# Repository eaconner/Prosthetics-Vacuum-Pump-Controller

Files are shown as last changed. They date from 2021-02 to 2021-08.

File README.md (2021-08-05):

# Prosthetics Vacuum Pump Controller

## Introduction

Designed to maintain a set vacuum pressure for prosthetic arms and legs.

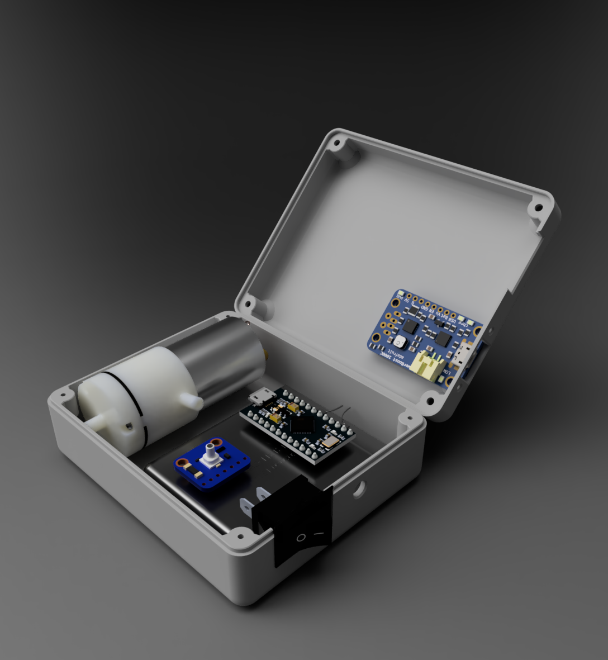
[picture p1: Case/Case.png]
3D Printed Case


## Dependencies

[Adafruit MPRLS Library](https://github.com/adafruit/Adafruit_MPRLS)

## Author

Eric Conner (Eric@EricConner.net)

## License

### MIT license

Permission is hereby granted, free of charge, to any person obtaining a copy of this software and associated documentation files (the "Software"), to deal in the Software without restriction, including without limitation the rights to use, copy, modify, merge, publish, distribute, sublicense, and/or sell copies of the Software, and to permit persons to whom the Software is furnished to do so, subject to the following conditions:

The above copyright notice and this permission notice shall be included in all copies or substantial portions of the Software.

THE SOFTWARE IS PROVIDED "AS IS", WITHOUT WARRANTY OF ANY KIND, EXPRESS OR IMPLIED, INCLUDING BUT NOT LIMITED TO THE WARRANTIES OF MERCHANTABILITY, FITNESS FOR A PARTICULAR PURPOSE AND NONINFRINGEMENT. IN NO EVENT SHALL THE AUTHORS OR COPYRIGHT HOLDERS BE LIABLE FOR ANY CLAIM, DAMAGES OR OTHER LIABILITY, WHETHER IN AN ACTION OF CONTRACT, TORT OR OTHERWISE, ARISING FROM, OUT OF OR IN CONNECTION WITH THE SOFTWARE OR THE USE OR OTHER DEALINGS IN THE SOFTWARE.

## Changes

- 2021.0628.0 - Added min/max set points
- 2021.0221.0 - Revised Pump class to define pump pin when pump is initilized
- 2021.0220.0 - Set DEBUG to false and misc. other changes
- 2021.0219.0 - Added option to specify on and off times for Pump
- 2021.0218.1 - Added destructor for Pump class
- 2021.0218.0 - Initial release

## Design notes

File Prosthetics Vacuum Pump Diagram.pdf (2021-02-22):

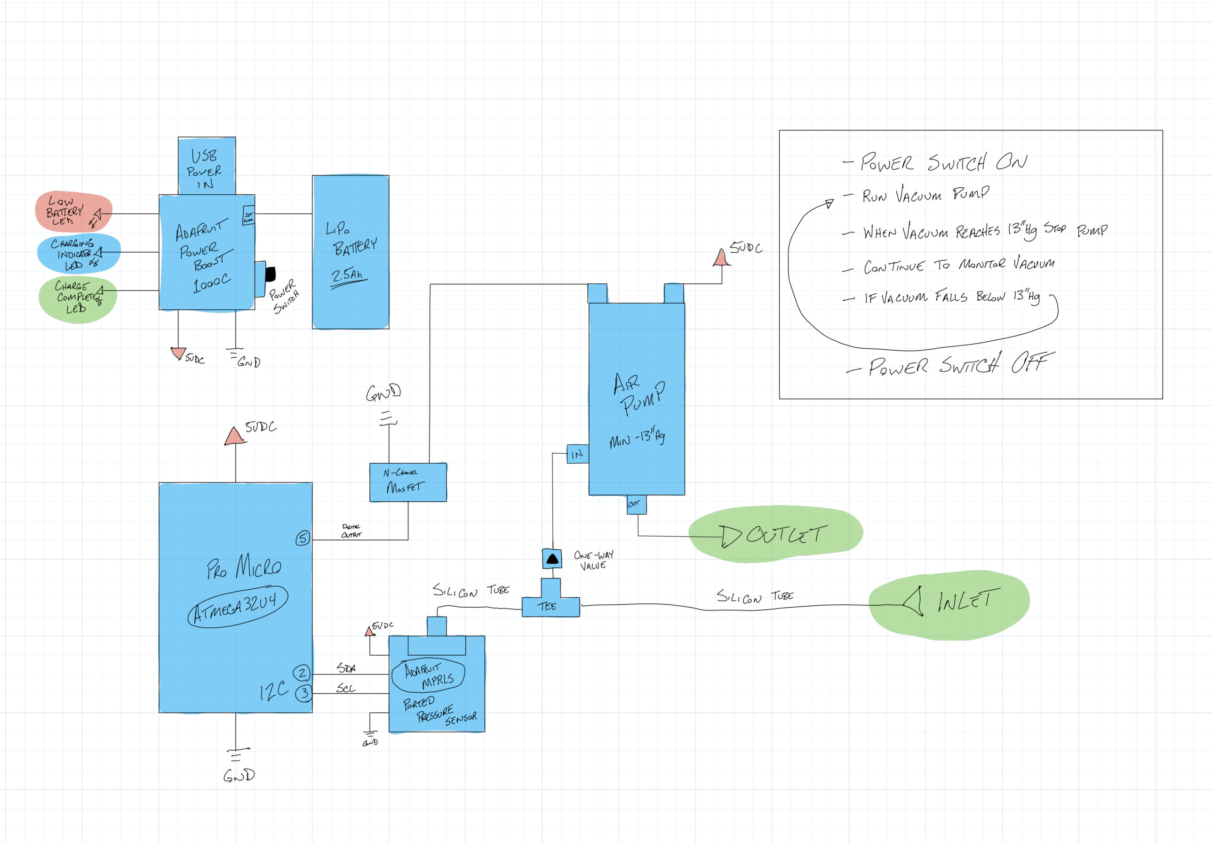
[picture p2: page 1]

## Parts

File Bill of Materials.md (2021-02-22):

# Prosthetics Vacuum Pump Controller

## Bill of Materials

- [Adafruit PowerBoost 1000 Charger](https://www.adafruit.com/product/2465)
- [Adafruit MPRLS Ported Pressure Sensor Breakout](https://www.adafruit.com/product/3965)
- [Air Pump and Vacuum DC Motor](https://www.adafruit.com/product/4699)
- [Silicone Tubing for Air Pumps and Valves - 3mm ID](https://www.adafruit.com/product/4661)
- [T-Connector For Silicone Tubing](https://www.adafruit.com/product/4662)
- [Lithium Ion Polymer Battery - 3.7v 2500mAh](https://www.adafruit.com/product/328)
- [N-channel power MOSFET - 30V / 60A](https://www.adafruit.com/product/355)
- [Pro Micro 5V 16MHz Development Board](https://amazon.com/gp/product/B07FXCTVQP)
- [SPST Toggle Switch](https://amazon.com/gp/product/B08F816MB4)
- [4mm Check Valve](https://www.amazon.com/gp/product/B08HYVKTLX)

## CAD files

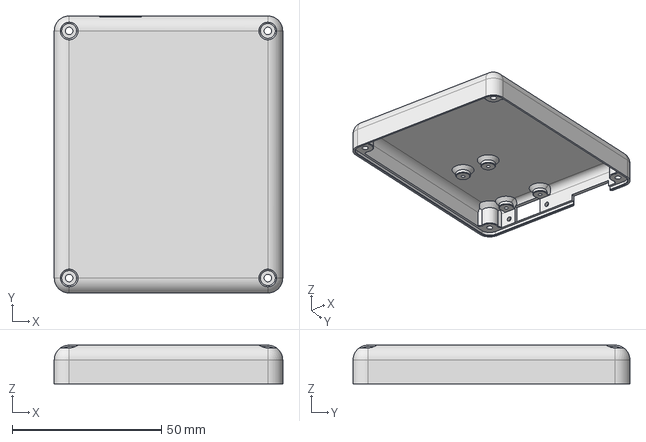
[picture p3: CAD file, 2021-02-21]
Case/Top.step
76.7 x 92.9 x 13.0 mm

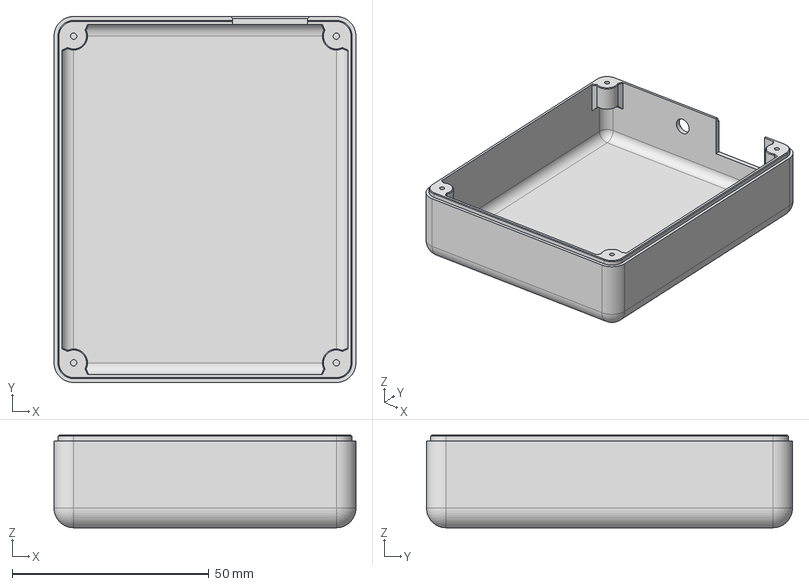
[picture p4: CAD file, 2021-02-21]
Case/Bottom.step
76.7 x 92.9 x 23.5 mm

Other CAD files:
Case/Bottom.stl
Case/Top.stl

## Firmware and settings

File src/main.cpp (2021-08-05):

/**
 * @file main.cpp
 * 
 * @author Eric Conner (Eric@EricConner.net)
 * @version 2021.0628.0
 * @copyright Copyright (c) 2021
 * 
 * @mainpage Prosthetics Vacuum Pump Controller
 * 
 * @section introduction Introduction
 * 
 * Designed to maintain a set vacuum pressure for prosthetic arms and legs.
 * 
 * @section dependencies Dependencies
 * 
 * [Adafruit MPRLS Library] (https://github.com/adafruit/Adafruit_MPRLS)
 * 
 * @section author Author
 * 
 * Eric Conner (Eric@EricConner.net)
 * 
 * @section license License
 * 
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
 * The above copyright notice and this permission notice shall be included in all copies or substantial portions of the Software.
 * 
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
 * @section changes Changes
 * 
 * 2021.0628.0 - Added min/max set points
 * 
 * 2021.0221.0 - Revised Pump class to define pump pin when pump is initilized
 * 
 * 2021.0220.0 - Set DEBUG to false and misc. other changes
 * 
 * 2021.0219.0 - Added option to specify on and off times for Pump
 * 
 * 2021.0218.1 - Added destructor for Pump class
 * 
 * 2021.0218.0 - Initial release
 */

#include "main.h"
#include "pump.h"

Adafruit_MPRLS mpr = Adafruit_MPRLS();  // Initilize the Pressure Sensor
Pump pump = Pump(pumpPin);  // Initilize the Pump

/**
 * @brief Standard Arduino setup function, this initilizes everything and then jumps to loop().
 */
void setup() {
    if (DEBUG) {
        Serial.begin(115200);  // Setup serial connection for displaying text if we are in debug mode
        Serial.println("Prosthetic Vacuum Pump - v2021.0628.0");
    }

    // Start the MPRLS pressure sensor
    if(!mpr.begin()) {
        // Wait for sensor to connect
        while(1) {
            delay(10);
            Serial.println("Waiting for sensor...");
        }
    }

   delay(2500);

   wdt_reset();
   wdt_enable(WDTO_2S);
}

/**
 * @brief Standard Arduino loop fuction, this is our main code loop.
 */
void loop() {
    if (getPressure() >= setMaxPressure) {  // If the pressure is greater than the setMinPressure turn the pump on.
        pump.On();
    }

    if (getPressure() <= setMinPressure) {  // If the pressure is greater than the setMaxPressure turn the pump off.
        pump.Off();
    }

    delay(750);
    wdt_reset();
}

/**
 * @brief Get the Pressure value from the Pressure Sensor in hPa.
 * 
 * @return float 
 */
float getPressure() {
    float pressure_hPa = mpr.readPressure();

    if (DEBUG) {
        Serial.print("Pressure (hPa): ");
        Serial.println(pressure_hPa);
    }

    return pressure_hPa;  // Return the pressure value
}

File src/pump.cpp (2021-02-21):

/**
 * @file pump.cpp
 * 
 * @author Eric Conner (Eric@EricConner.net)
 * @copyright Copyright (c) 2021
 * 
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
 * The above copyright notice and this permission notice shall be included in all copies or substantial portions of the Software.
 * 
 * THE SOFTWARE IS PROVIDED "AS IS", WITHOUT WARRANTY OF ANY KIND, EXPRESS OR IMPLIED, INCLUDING BUT NOT LIMITED TO THE WARRANTIES OF
 * MERCHANTABILITY, FITNESS FOR A PARTICULAR PURPOSE AND NONINFRINGEMENT. IN NO EVENT SHALL THE AUTHORS OR COPYRIGHT HOLDERS BE LIABLE FOR
 * ANY CLAIM, DAMAGES OR OTHER LIABILITY, WHETHER IN AN ACTION OF CONTRACT, TORT OR OTHERWISE, ARISING FROM, OUT OF OR IN CONNECTION WITH
 * THE SOFTWARE OR THE USE OR OTHER DEALINGS IN THE SOFTWARE.
 */

#include "pump.h"

/**
 * @brief Construct a new Pump::Pump object
 * 
 * @param pumpPin Output pin that the pump is connected to
 * @param onTime Maximum time to run the pump in milliseconds, default: 10,000
 * @param offTime Minimum time to stop the pump to cool down, default: 5,000
 */
Pump::Pump(int pumpPin, unsigned short onTime, unsigned short offTime) {
    Pump::pumpPin = pumpPin;
    Pump::onTimer = 0;  // Reset onTimer to 0
    Pump::offTimer = 0;  // Reset offTimer to 0
    Pump::status = STOPPED;
    Pump::maxOnTime = onTime;
    Pump::minOffTime = offTime;
    pinMode(Pump::pumpPin, OUTPUT);  // Setup the output pin for Pump
    digitalWrite(Pump::pumpPin, LOW);  // Seting the Pump output pin LOW turns the Pump off
}

/**
 * @brief Destroy the Pump::Pump object
 */
Pump::~Pump() {
    digitalWrite(Pump::pumpPin, LOW);  // Seting the Pump output pin LOW turns the Pump off
    Pump::status = STOPPED;
}

/**
 * @brief Call for the pump to turn on, will only turn on if it has been off for at least 5 seconds
 */
void Pump::On() {
    // If the pump is off and cooled down turn the pump on, set the status to running and start the running timer
    if (Pump::status == STOPPED) {
        digitalWrite(Pump::pumpPin, HIGH);
        Pump::status = RUNNING;
        Pump::onTimer = millis();
    }
    
    if (Pump::status == RUNNING) {
        // If the pump has been running for 10 seconds turn it off to prevent overheating
        if (millis() - Pump::onTimer >= Pump::maxOnTime) {
            Pump::Off();
        }
    }

    if (Pump::status == COOLDOWN) {
        // If the pump has been cooled down for 5 seconds set the status to stopped
        if (millis() - Pump::offTimer >= Pump::minOffTime) {
            Pump::status = STOPPED;
        }
    }
}

/**
 * @brief Call for the pump to instantly turn off
 */
void Pump::Off() {
    // If the pump is running turn it off and start the cooldown timer
    if (Pump::status == RUNNING) {
        digitalWrite(Pump::pumpPin, LOW);
        Pump::offTimer = millis();
        Pump::status = COOLDOWN;
    }
    
    if (Pump::status == COOLDOWN) {
        // If the pump has been cooled down for 5 seconds set the status to stopped
        if (millis() - Pump::offTimer >= Pump::minOffTime) {
            Pump::status = STOPPED;
        }
    }
}

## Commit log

2021-02-18 Added destructor for pump class
2021-02-19 Added option to specify on and off times for Pump
2021-02-21 Added Bill of Materials
2021-02-21 Added doxygen brief for Pump class
2021-02-21 Revised Pump to define pin when initilized
2021-02-21 Added case STL and STEP files
    [Bottom.step, Bottom.stl, Top.step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]
2021-08-05 Missed version number in debug print
    [main.cpp]
